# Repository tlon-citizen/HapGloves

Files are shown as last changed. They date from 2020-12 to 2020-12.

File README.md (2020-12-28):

# HapGloves
<b>Vibrotactile Gloves for 3D Interaction</b>

The HapGloves are a pair of gloves for 3D interaction. They rely on hand tracking (i.e., Leap Motion) to provide vibrotactile feedback on fingers and palm surface. The device contains 14 LRA actuators (PMC10-100)[1] for each hand, driven independently with PWM signals and managed wirelessly from the computer using Bluetooth Low Energy technology. 
All the electronics and power sources are enclosed in a fore-arm band, offering freedom of movement and comfort for common hand-interaction tasks in VR environments.
The actuators are controlled by an Adafruit 16-channel 12-bit pulse width modulation (PWM) driver[2]. A self-made circuit board organizes the connections, provides signal enhancements (including amplifying, basic active breaking, and basic overdriving), and fits directly onto the PWM driver. 
Each glove is powered by a 3.7V lithium polymer ion (LiPo) rechargeable battery. 
To mount the circuitry around the arm, all the components are installed in a 3D-printed case, which can be attached to a neoprene arm belt.

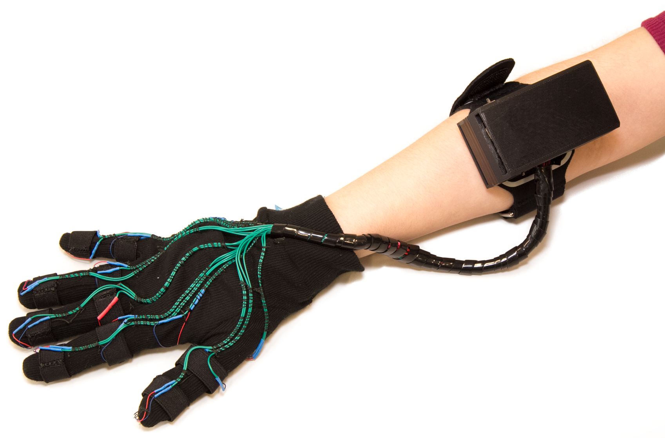
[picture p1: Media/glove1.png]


This repository contains the necessary files to build a new device; model files for 3D printing, schematics for electronics, and embedded/testing code.



Inducing Body-Transfer Illusions in VR by Providing Brief Phases of Visual-Tactile Stimulation<br/>
Oscar Ariza, Jann Freiwald, Nadine Laage, Michaela Feist, Mariam Salloum, Gerd Bruder, Frank Steinicke<br/>
Proceedings of the ACM Symposium on Spatial User Interaction<br/>
2016

[1] http://www.precisionmicrodrives.com/<br>
[2] https://www.adafruit.com/product/815

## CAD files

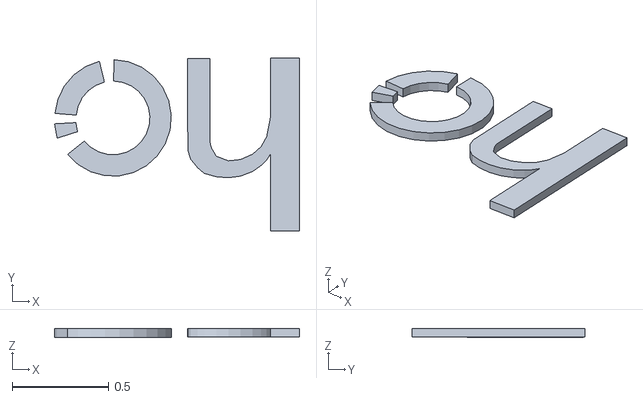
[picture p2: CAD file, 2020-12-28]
3DModel/hciLogo.stl
1.27 x 0.897 x 0.0469

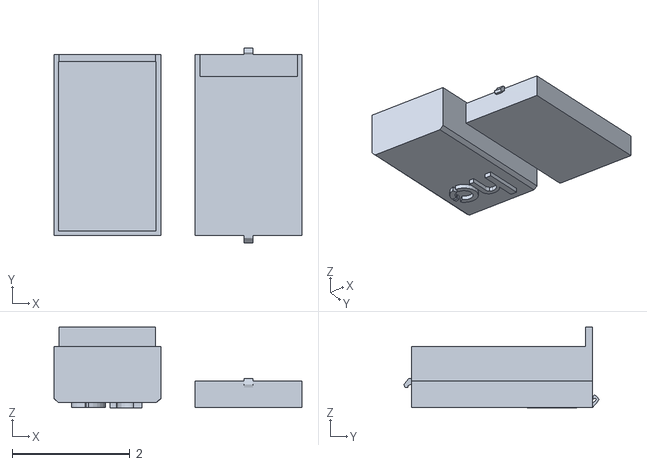
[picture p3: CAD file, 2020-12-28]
3DModel/HapGlove.stl
4.21 x 3.31 x 1.37

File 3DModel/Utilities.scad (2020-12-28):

module roundedCube(w,h,d,dia) {
    hull()
    {
        sphere(d=dia);
        translate([0,h,d])sphere(d=dia);
        translate([w,0,d])sphere(d=dia);
        translate([w,h,0])sphere(d=dia);
        translate([w,h,d])sphere(d=dia);
        translate([0,0,d])sphere(d=dia);
        translate([w,0,0])sphere(d=dia);
        translate([0,h,0])sphere(d=dia);
    }
}

module arrow() {
    base=4;
    peak=base/2;
    thickness=0.5;
    union()
    {
        cube([base/2, base/2, thickness], center=true);
        translate([-base/2, peak/2, -thickness/2])
            polyhedron // triangle
            (
                points = 
                [
                    [0,0,0], 
                    [base, 0, 0], 
                    [base/2, peak, 0],
                    [0,0,thickness], 
                    [base, 0, thickness], 
                    [base/2, peak, thickness]
                ],
                faces = 
                [
                    [2, 1, 0], 
                    [0, 1, 4, 3],
                    [1, 2, 5, 4],
                    [5, 2, 0, 3],
                    [3, 4, 5]
                ]
            );
    }
}

module extrudedTriangle(base, thickness) {
    peak=base/2;
    rotate([0.0, 0.0, 45.0])
    polyhedron // triangle
    (
        points = 
        [
            [0,0,0], 
            [base, 0, 0], 
            [base/2, peak, 0],
            [0,0,thickness], 
            [base, 0, thickness], 
            [base/2, peak, thickness]
        ],
        faces = 
        [
            [2, 1, 0], 
            [0, 1, 4, 3],
            [1, 2, 5, 4],
            [5, 2, 0, 3],
            [3, 4, 5]
        ]
    );
}

module hole(x, y, z) {
    translate([x, y, z])
    {
        color("Red", 1.0)
        rotate([0, 0, 180.0])
        cylinder(h=3, r=0.4, center=true);
    }
}

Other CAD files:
3DModel/hciLogo.blend

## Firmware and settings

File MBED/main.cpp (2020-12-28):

/* Haptics Micro-controller Library
 * UHH HCI 2015
 * ariza@informatik.uni-hamburg.de
 */

#include "mbed.h"
#include "BLEDevice.h"
#include "HapticsController.h"
    
BLEDevice  ble;

static volatile bool triggerSensorPolling = false;

void disconnectionCallback(Gap::Handle_t handle, Gap::DisconnectionReason_t reason)
{
    ble.startAdvertising(); // restart advertising
}

void onConnectionCallback(Gap::Handle_t handle, Gap::addr_type_t peerAddrType, const Gap::address_t peerAddr, const Gap::ConnectionParams_t *params)
{
    Gap::ConnectionParams_t cparams;
    ble.getPreferredConnectionParams(&cparams);
    
    Gap::ConnectionParams_t gap_conn_params;
    gap_conn_params.minConnectionInterval        = 16;
    gap_conn_params.maxConnectionInterval        = 16;
    gap_conn_params.connectionSupervisionTimeout = cparams.connectionSupervisionTimeout;
    gap_conn_params.slaveLatency                 = cparams.slaveLatency;
    
    ble.updateConnectionParams(handle, &gap_conn_params);
}

void periodicCallback(void)
{
    //led1 = !led1;
    triggerSensorPolling = true;
}

int main(void)
{
    led1 = 1;
    
    Ticker ticker;
    ticker.attach(periodicCallback, 0.05);

    ble.init();
    ble.onDisconnection(disconnectionCallback);
    ble.onConnection(onConnectionCallback);
    
    HCIHapticService hciHapticsService(ble, "UHH", "HCI", "HAPTICS", "hw-rev1", "fw-rev1", "soft-rev1" );
    
    const char DEVICE_NAME[]     = "HCI_HapGLeft";
    const uint16_t uuid16_list[] =   
    {
        GattService::UUID_HUMAN_INTERFACE_DEVICE_SERVICE
        ,GattService::UUID_DEVICE_INFORMATION_SERVICE
    };
        
    /* Setup advertising. */
    ble.accumulateAdvertisingPayload(GapAdvertisingData::BREDR_NOT_SUPPORTED | GapAdvertisingData::LE_GENERAL_DISCOVERABLE);
    ble.accumulateAdvertisingPayload(GapAdvertisingData::COMPLETE_LIST_16BIT_SERVICE_IDS, (uint8_t *)uuid16_list, sizeof(uuid16_list));
    ble.accumulateAdvertisingPayload(GapAdvertisingData::HUMAN_INTERFACE_DEVICE_HID);
    ble.accumulateAdvertisingPayload(GapAdvertisingData::COMPLETE_LOCAL_NAME, (uint8_t *)DEVICE_NAME, sizeof(DEVICE_NAME));
    ble.setAdvertisingType(GapAdvertisingParams::ADV_CONNECTABLE_UNDIRECTED);
    ble.setAdvertisingInterval(Gap::MSEC_TO_ADVERTISEMENT_DURATION_UNITS(1000));
    ble.startAdvertising();

    while (true) 
    {
        if (triggerSensorPolling && ble.getGapState().connected) 
        {
            triggerSensorPolling = false;
            
            hciHapticsService.processInputs();
        } 
        else 
        {
            ble.waitForEvent();
        }
    }
}
